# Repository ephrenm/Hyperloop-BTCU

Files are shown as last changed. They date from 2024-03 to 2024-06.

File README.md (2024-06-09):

# Hyperloop-BTCU (Battery Temperature Control Unit)
Simple controller board designed to monitor and control high voltage battery temperature using the R7FA4M1 32-bit MCU from Renesas.

Hyperloop_BTCU-PCB

Designed using Altium Designer by Ephren Manning.

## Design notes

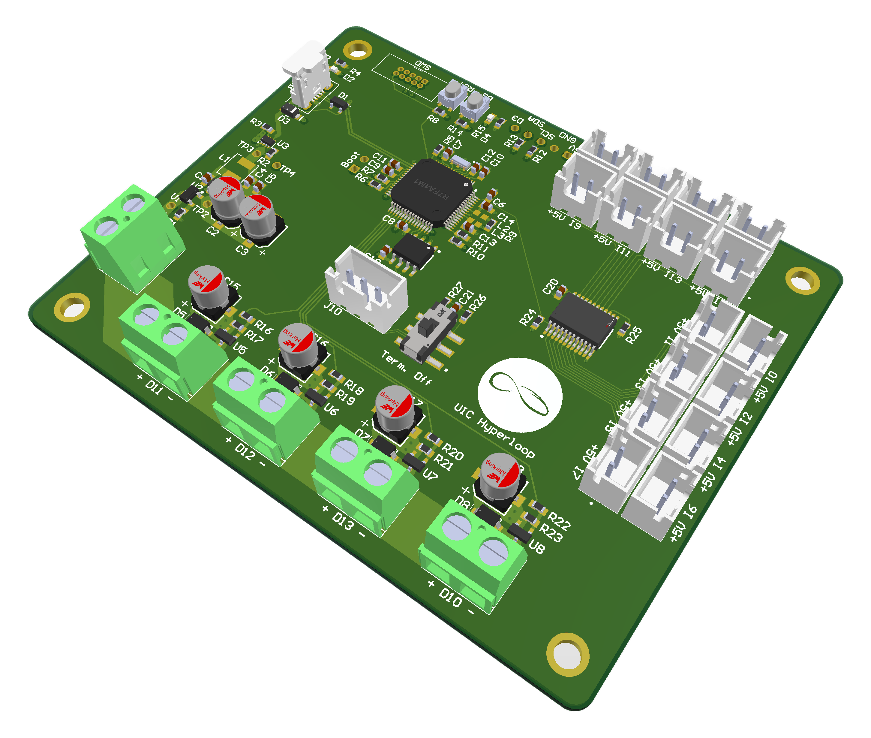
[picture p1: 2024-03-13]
Hyperloop_BTCU-RevA Project Files/Misc Project Files/Hyperloop_BTCU-PCB.png

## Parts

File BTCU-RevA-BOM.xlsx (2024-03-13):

Designator | Quantity | Manufacturer 1 | Manufacturer Part Number 1
C1, C6, C7, C8, C10, C13, C19, C20 | 8 | Samsung Electro-Mechanics | CL10B104KO8NNNC
C2, C3 | 2 | Wurth Electronics | 865230542002
C4, C5 | 2 | Samsung Electro-Mechanics | CL10A226MP8NUNE
C9, C11, C12 | 3 | Samsung Electro-Mechanics | CL10A475KP8NNNC
C14 | 1 | Samsung Electro-Mechanics | CL10B105KP8NNNC
C15, C16, C17, C18 | 4 | Wurth Electronics | 865080442004
C21 | 1 | Walsin Technology Corporation | 0603B472K160CT
D1 | 1 | Nexperia USA Inc. | PRTR5V0U2X,215
D2, D4 | 2 | Lite-On Inc. | LTST-C191KGKT
D3 | 1 | Nexperia | PMEG6020AELRX
D5, D6, D7, D8 | 4 | SMC Diode Solutions | 1N4007FL
J1, J6, J7, J8, J9 | 5 | TE Connectivity | 282837-2
J2 | 1 | Molex | 1051330001
J3 | 1 | CNC Tech | 3221-10-0100-00
J10 | 1 | JST Sales | B3B-XH-A
J11, J12, J13, J14, J15, J16, J17, J18, J19, J20, J21, J22, J23, J24, J25, J26 | 16 | JST Sales America | B2B-XH-A
L1 | 1 | Bourns Electronics | SRP0415-4R7K
L2, L3 | 2 | Murata | BLM18PG471SN1D
R1, R16, R18, R20, R22 | 5 | YAGEO | RC0603FR-071KL
R2, R3, R5, R6, R7, R8, R9, R12, R13, R14, R25 | 11 | Yageo | RC0603FR-075K1L
R4, R15 | 2 | YAGEO | RC0603FR-07604RL
R10, R17, R19, R21, R23, R24 | 6 | Yageo | RC0603FR-07100KL
R11 | 1 | YAGEO | RC0603FR-0713K7L
R26, R27 | 2 | YAGEO | RC0603FR-0760R4L
SW1, SW2 | 2 | C&K | PTS810 SJM 250 SMTR LFS
SW3 | 1 | ITT C&K | JS202011SCQN
U1 | 1 | Diodes Incorporated | DMP3099L-7
U2 | 1 | Diodes | AP63205WU-7
U3 | 1 | Texas Instruments | TPS2116DRLR
U4 | 1 | Renesas | R7FA4M1AB3CFM#AA0
U5, U6, U7, U8 | 4 | Nexperia USA Inc. | PMV20XNER
U9 | 1 | NXP USA Inc. | TJA1051T/3,118
U10 | 1 | Texas Instruments | CD74HC4067SM96
Y1 | 1 | Murata Electronics | CSTNE12M0G55Z000R0

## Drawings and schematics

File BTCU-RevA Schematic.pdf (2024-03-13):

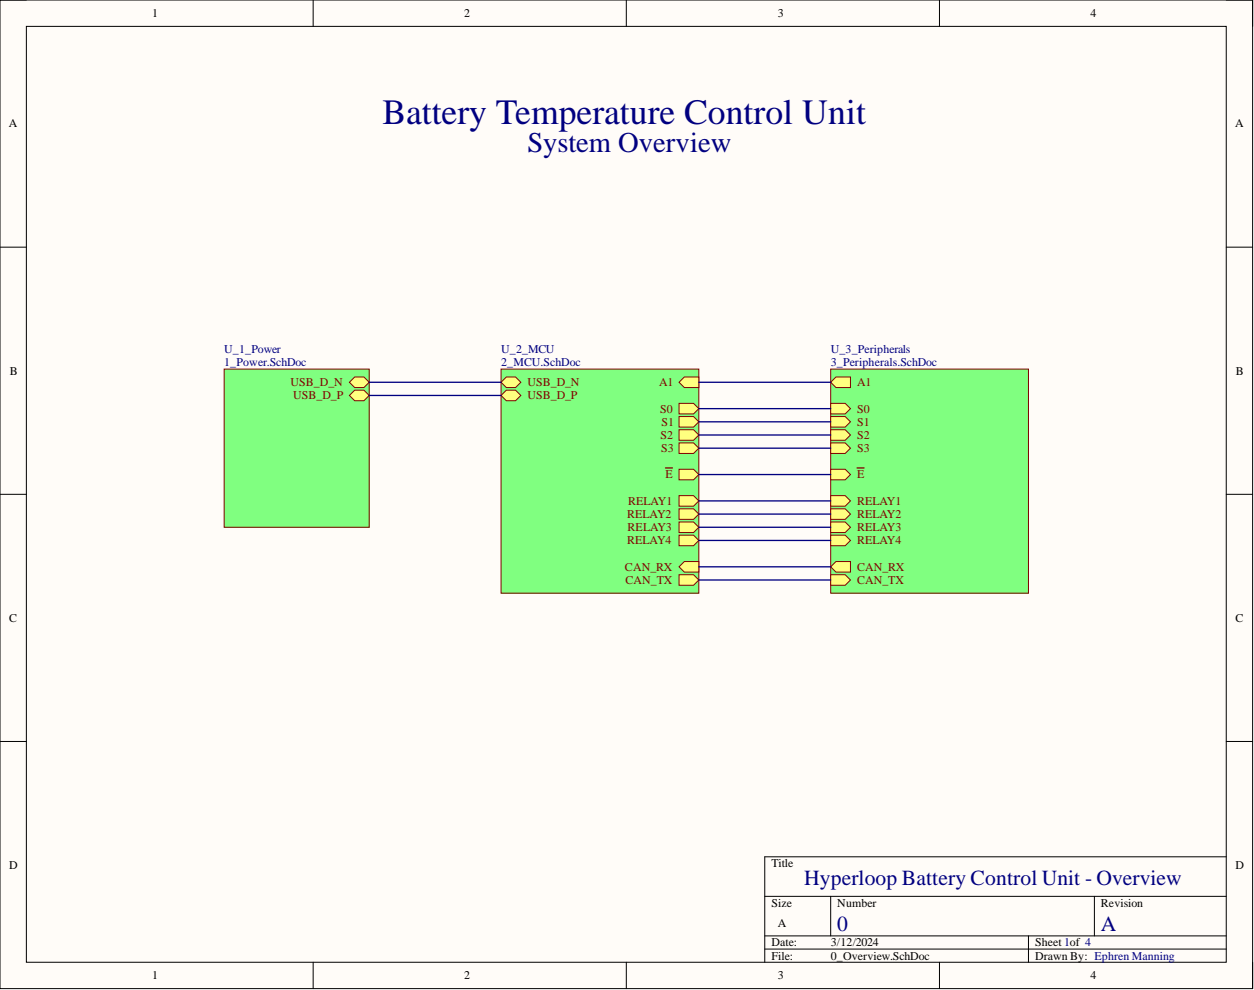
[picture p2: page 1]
Date:; Sheet of; File:; 0_Overview.SchDoc; Drawn By:; Ephren Manning; System Overview

Battery Temperature Control Unit

Title
Hyperloop Battery Control Unit - Overview

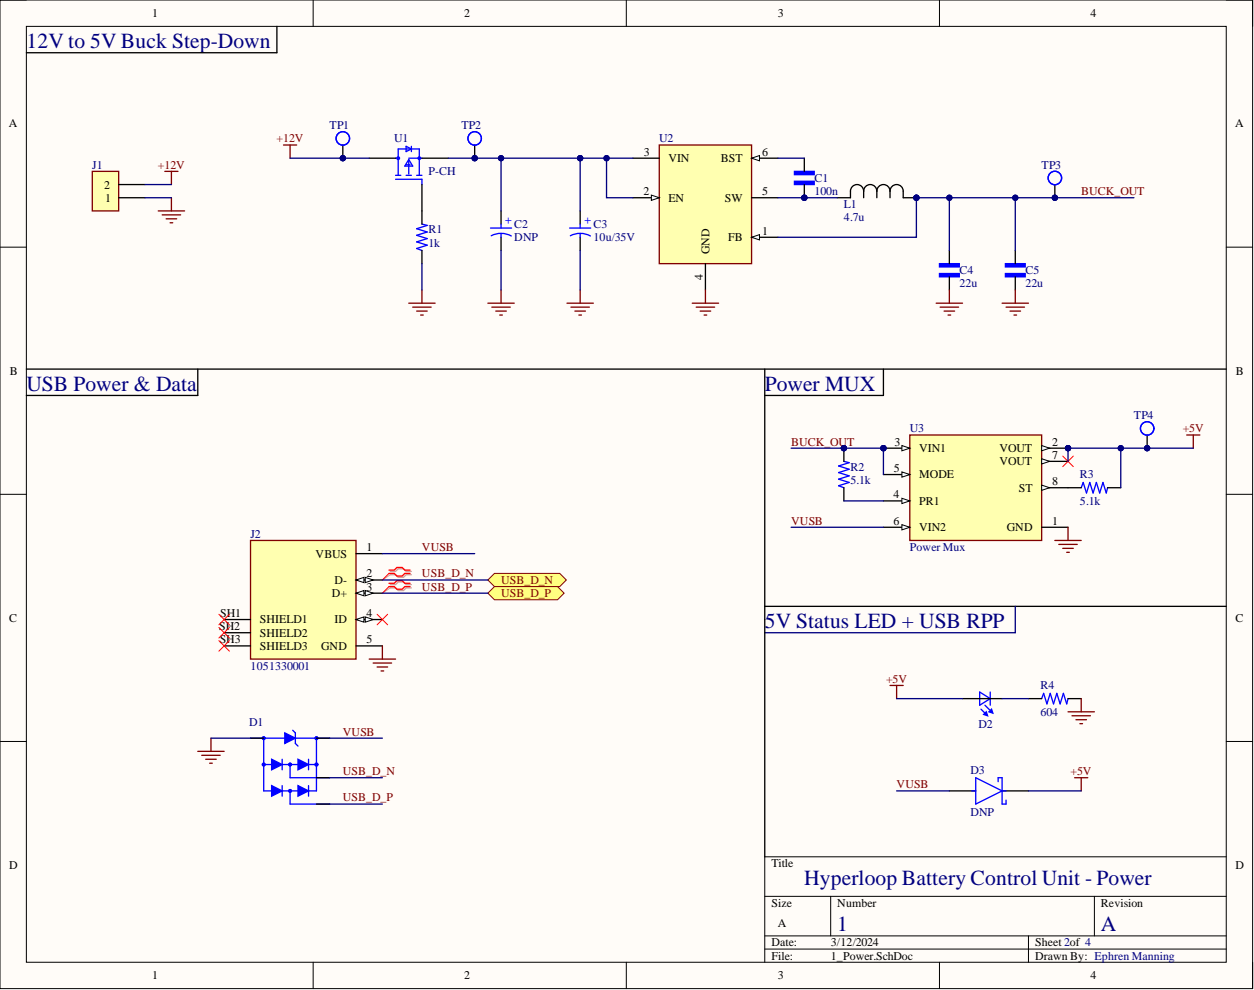
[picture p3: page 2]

12V to 5V Buck Step-Down

5V Status LED + USB RPP

Title
Hyperloop Battery Control Unit - Power

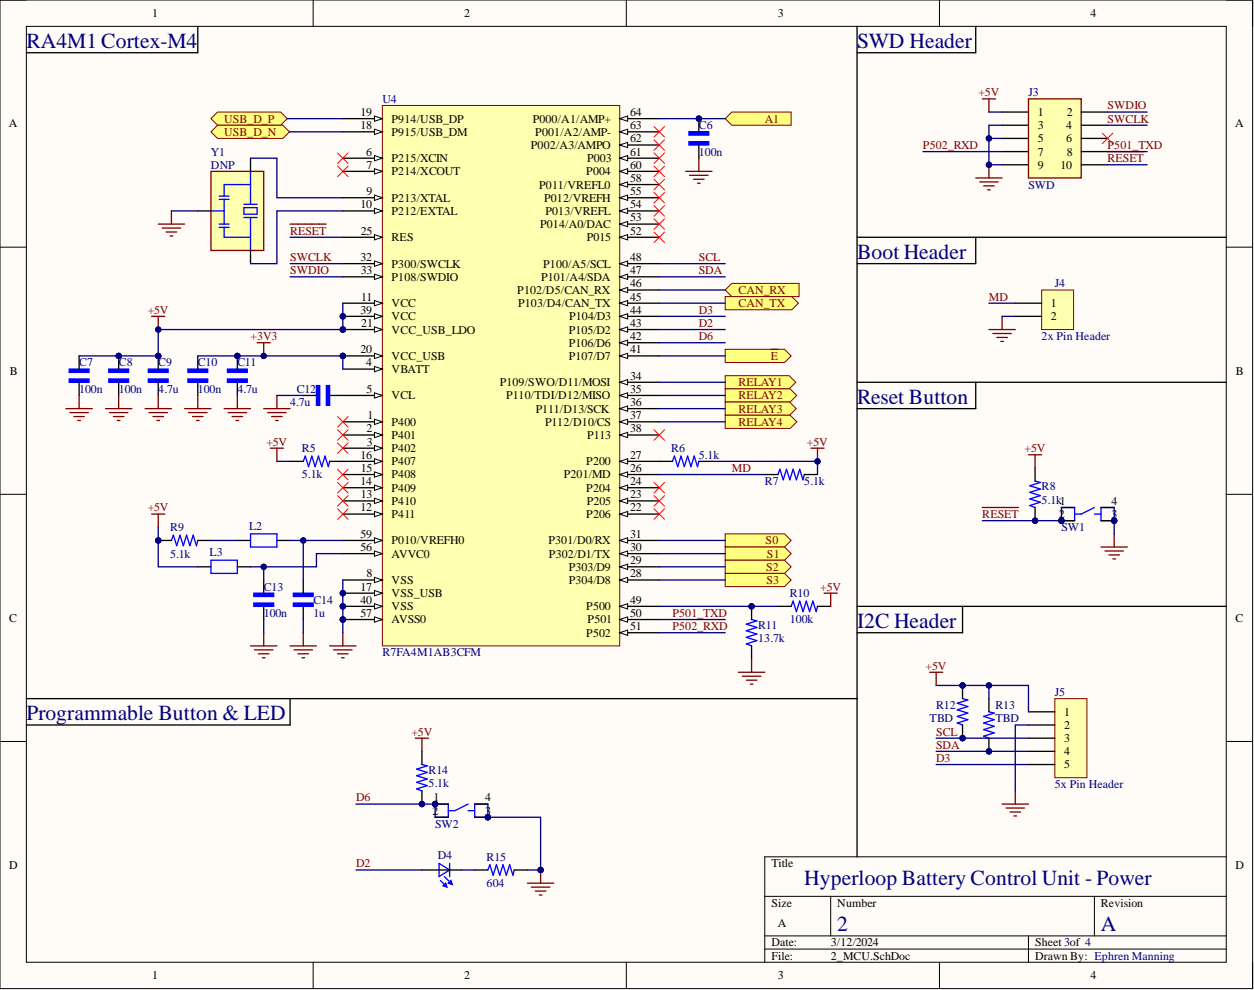
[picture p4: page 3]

P214/XCOUT 7

P212/EXTAL 10

RESET | RES 25

+3V3 | VCC_USB 20

C11 | VBATT 4

VSS 8

Title
Hyperloop Battery Control Unit - Power

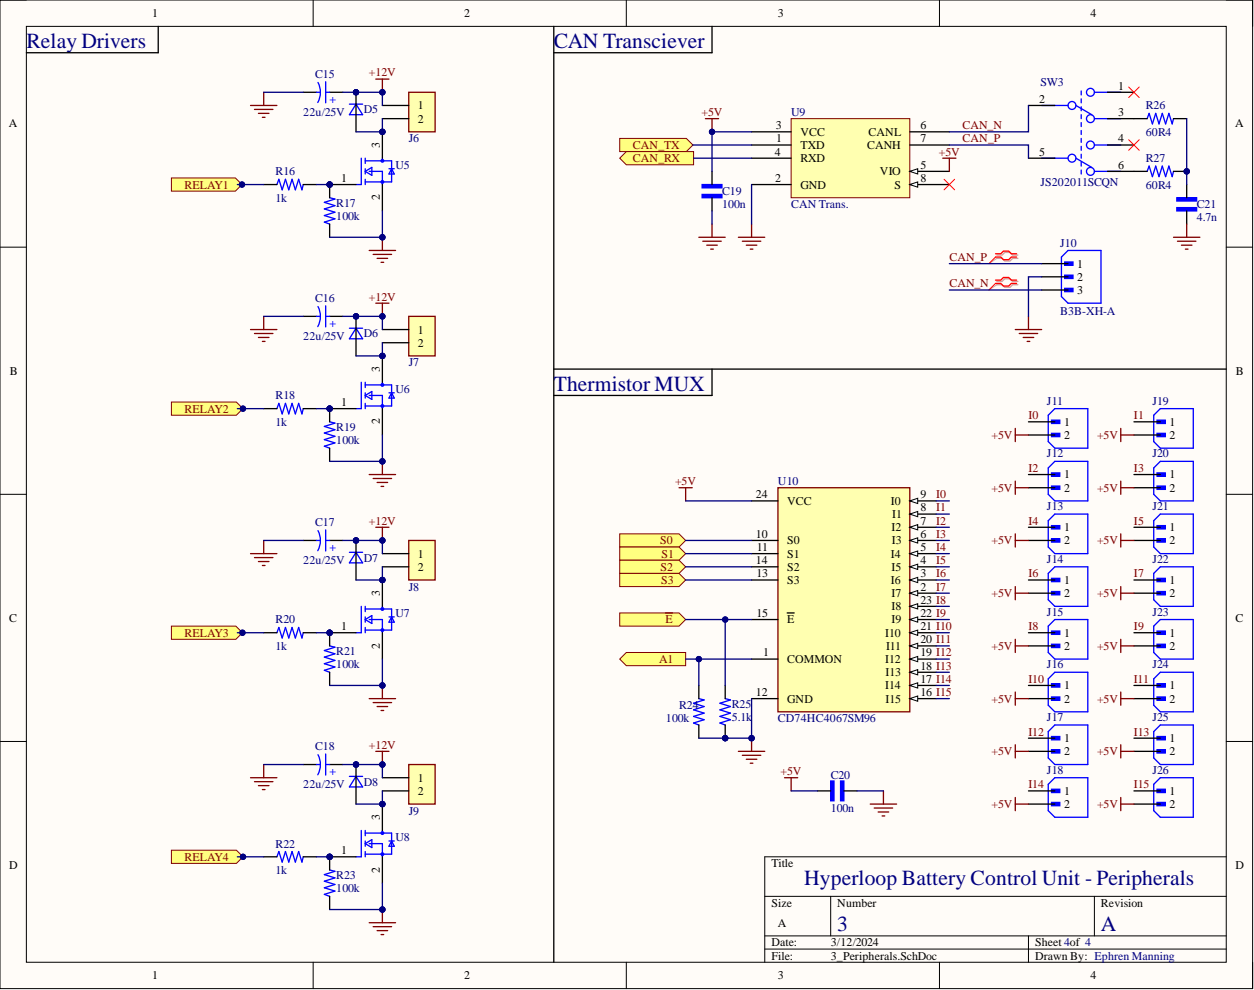
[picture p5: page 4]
1 SW3 JS202011SCQN C19 100n; Relay Drivers; CAN; Thermistor MUX; p Battery Co; hren Man

ntrol Unit - Perip

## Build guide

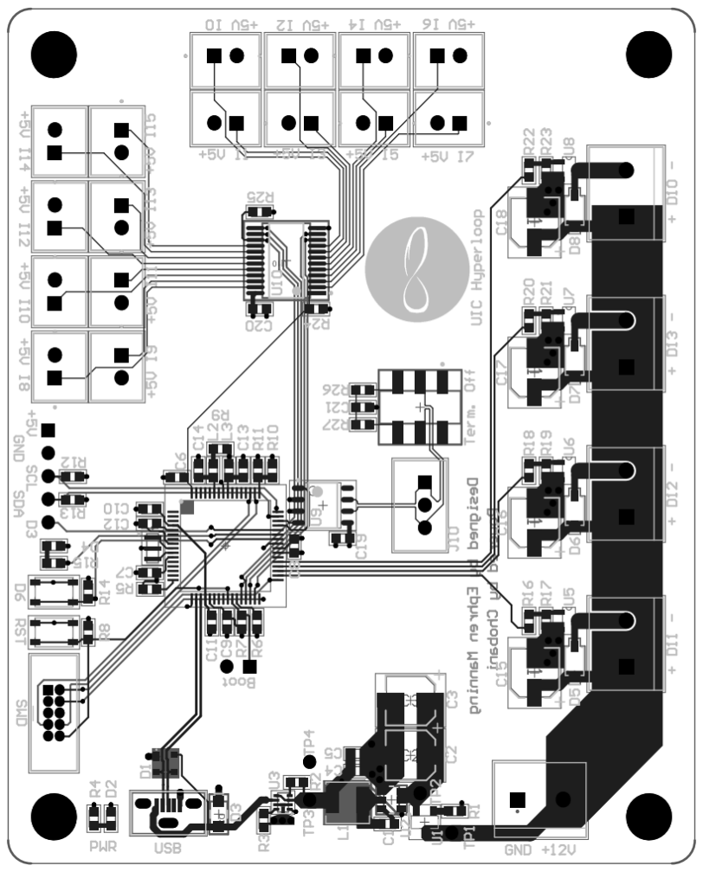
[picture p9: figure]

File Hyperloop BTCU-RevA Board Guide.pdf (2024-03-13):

# Battery Temperature Control Unit

# Board Manual - Rev A

Written by Ephren Manning

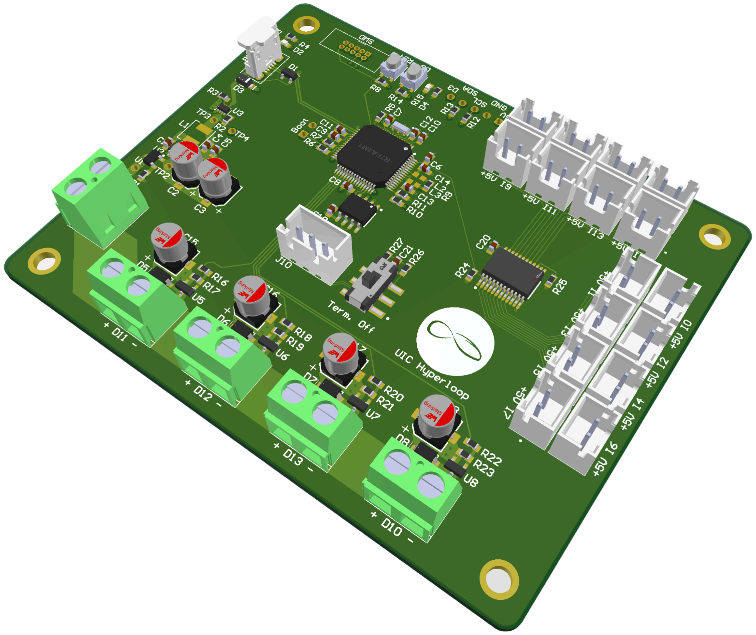
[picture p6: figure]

# Table of Contents

1. Pinouts
2. Overview
3. Power
4. Microcontroller
5. Peripherals
6. Schematics
7. Top-Down Copper View

# 1. Pinouts:

Hardware Pin | Pin Name | Arduino Pin | Function
28 | P304 | D8 | S3: Mux select bit 4, MSB
29 | P303 | D9 | S2: Mux select bit 3
30 | P302 | D1 | S1: Mux select bit 2
31 | P301 | D0 | S0: Mux select bit 1, LSB
41 | P107 | D7 | E: Mux enable, active low, pulled down
64 | P000 | A1 | A1: Analog input from mux
34 | P109 | D11 | RELAY1: Relay 1 enable, active high
35 | P110 | D12 | RELAY2: Relay 2 enable, active high
36 | P111 | D13 | RELAY3: Relay 3 enable, active high
37 | P112 | D10 | RELAY4: Relay 4 enable, active high
45 | P103 | D4 | CAN_RX: RX from CAN Trans.
46 | P102 | D5 | CAN_TX: TX to CAN Trans.
42 | P106 | D6 | D6: Connected to active-low button input
43 | P105 | D2 | D2: Connected to user LED
44 | P104 | D3 | D3: Connected to unused pin header
47 | P101 | A4/SDA | SDA: I2C broken out to unused pin header
48 | P100 | A5/SCL | SCL: I2C broken out to unused pin header

# 2. Overview

The Battery Temperature Control Unit, BTCU, is in charge of monitoring the temperature of 16 battery cells using NTC 100k thermistors and a 16:1 analog MUX. The thermistors are connected to the high side (+5V) of a resistor divider, with a 100k resistor on the low side. The resulting voltage is monitored by the microcontroller. The BTCU can react to over-temperature conditions by actuating 4 high voltage insulating relays which control the flow of battery current.

# 3. Power

The BTCU is designed to run off of 12V battery power. A buck converter regulates the input power to 5V for the microcontroller and other digital systems. A P-Channel
MOSFET provides reverse polarity protection to the buck-converter. The relay switching circuit delivers the unregulated 12V input to the relays when switched on. The relays are designed to work within the range of 12V to 24V, so some variation is okay. The BTCU can also be powered by USB. There is a TPS2116 Load Switch which chooses between the buck output or VUSB if both are connected simultaneously.

# 4. Microcontroller

The BTCU uses a 32-bit Cortex-M4 R7FA4M1AB3CFM. This microcontroller is 5V capable and designed to use the Arduino software core and bootloader. The Arduino bootloader can be flashed by pulling the MD pin to ground and following the steps at this link: https://docs.arduino.cc/tutorials/uno-r4-minima/cheat-sheet/#bootloader Alternatively, Renesas provides their own IDE called e2 Studio.

# 5. Peripherals

The 16:1 analog MUX is controlled by digital outputs S3-S0 to select one of 16 inputs. For example, S3S2S1S0 = 1010 results in COMMON -> I10.
There are also 4 active high relay control circuits, controlled by digital pins D10 to D13. BTCU also contains a TJA1051T/3 CAN Transceiver, with switchable 120 ohm termination. This is connected to the MCU’s on-chip CAN controller.

# 6. Schematics

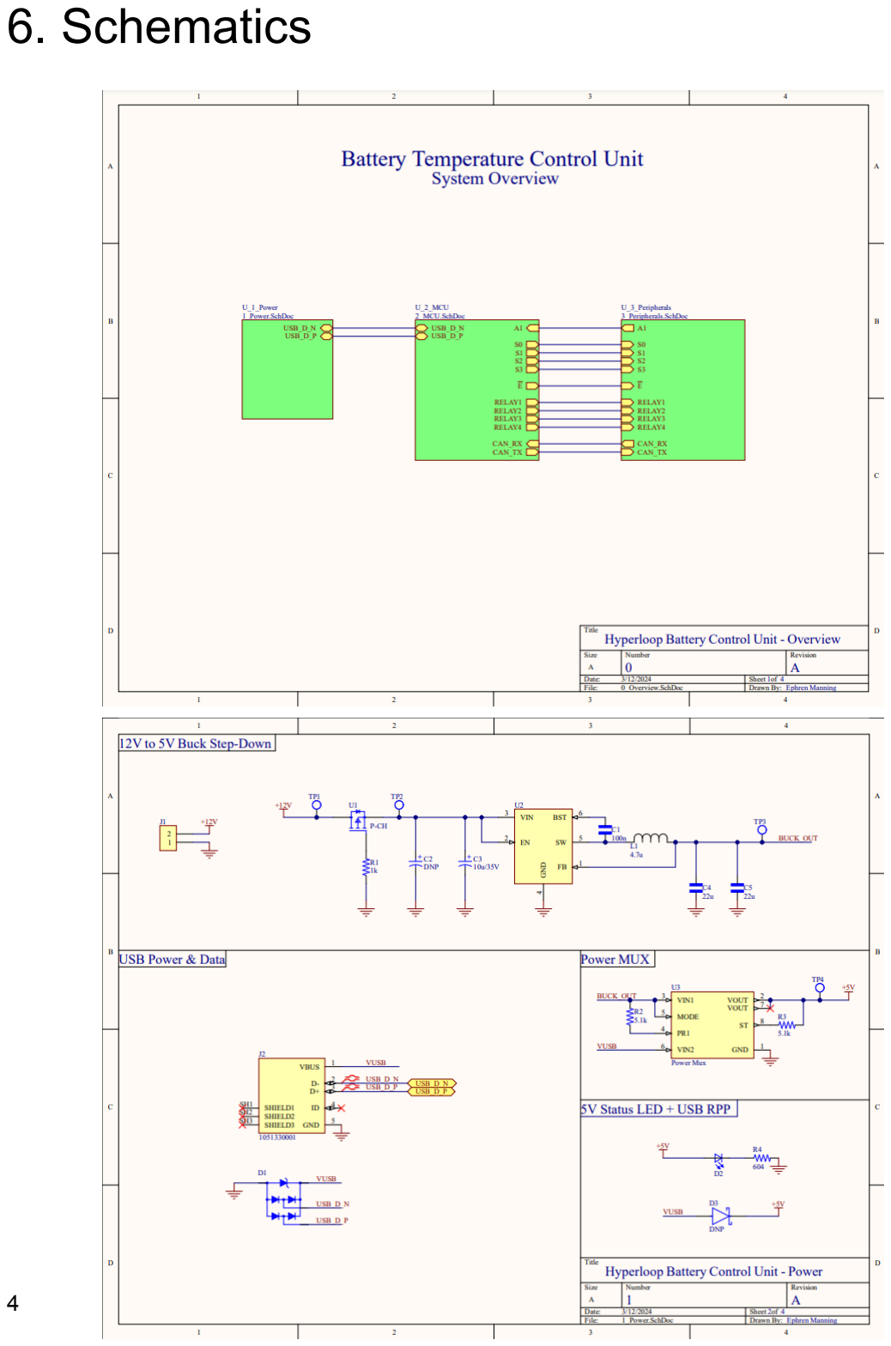
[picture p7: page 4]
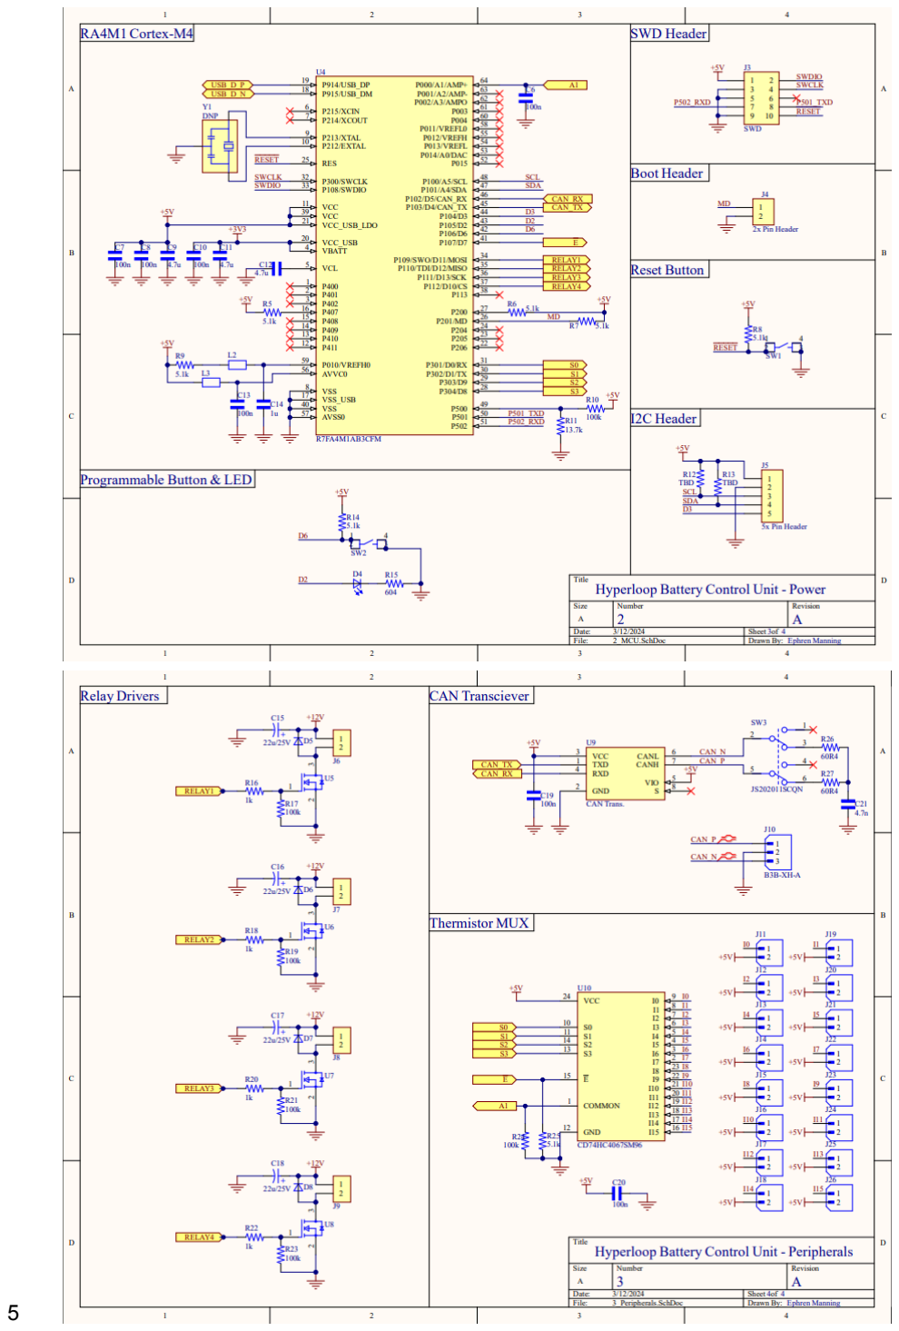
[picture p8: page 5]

# 7. Top-Down Copper View
